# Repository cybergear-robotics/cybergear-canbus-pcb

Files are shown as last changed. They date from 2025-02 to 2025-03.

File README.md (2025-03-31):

# CyberGear CAN-Bus PCB




This is a small extension board located on the CyberBot. It distributes the
CAN-bus to all 6 cybergears and provides a debug port. Each cybergear CAN-bus sink can
be switched between CAN-bus or debug port. The can-bus is designed as star
topology, which works in small setups. 

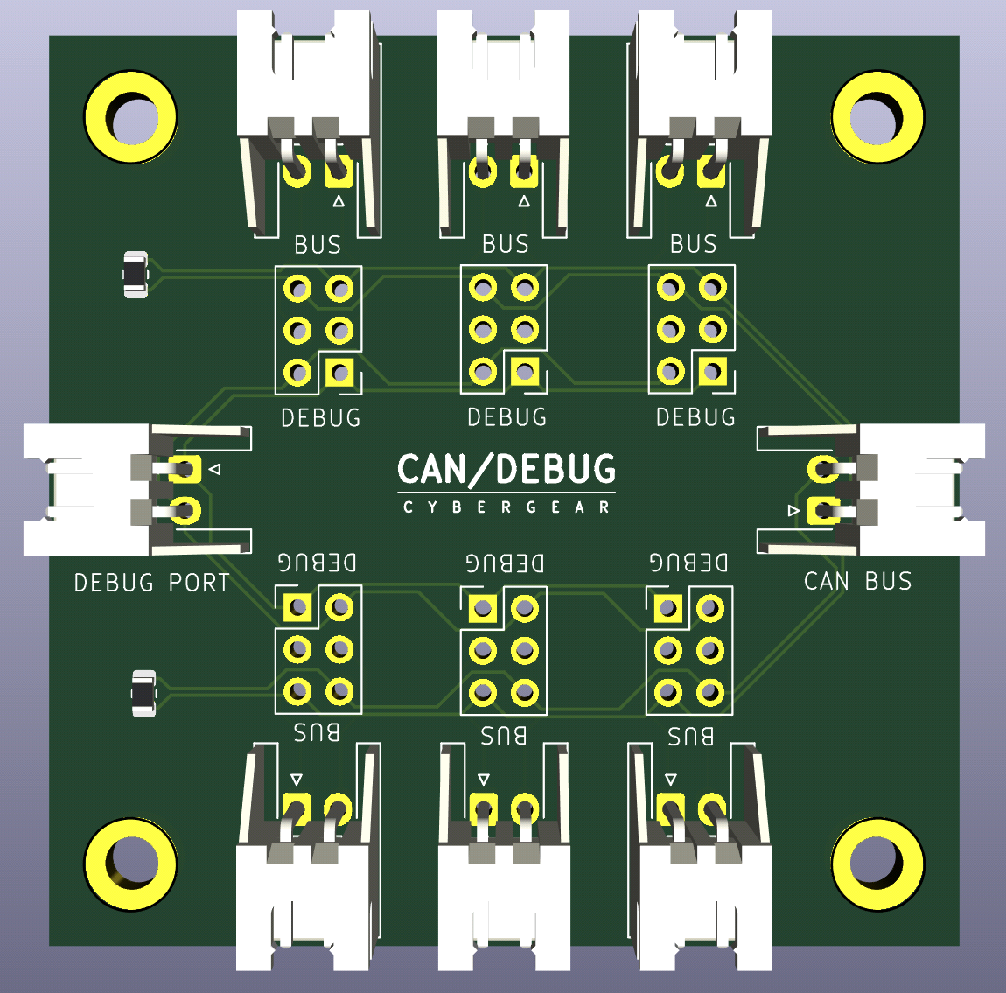
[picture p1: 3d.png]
3D


## DIP switches

The switches are missing in the production files and you need to solder these on your
own. The required switches are MSS22D18 Mini DIP Slide Switch 2x03.

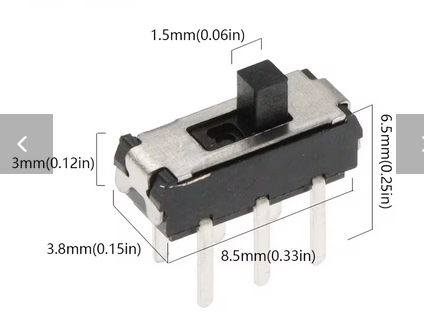
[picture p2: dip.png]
dip


## Debug Port

The debug port is connected to a special CAN to USB adapter. There is no product
number. I only could find one offer on Aliexpress for around 12 euros:

```
USB-TTL/RS232/RS485/CAN Serial Communication Module CH340 CP2102 Data Conversion
Transparent Transmission Standard Protocol
```

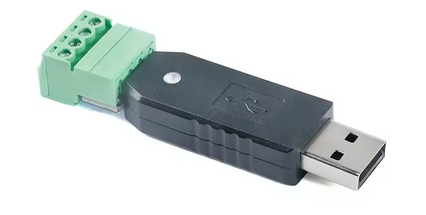
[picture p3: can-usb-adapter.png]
can-usb-adapter


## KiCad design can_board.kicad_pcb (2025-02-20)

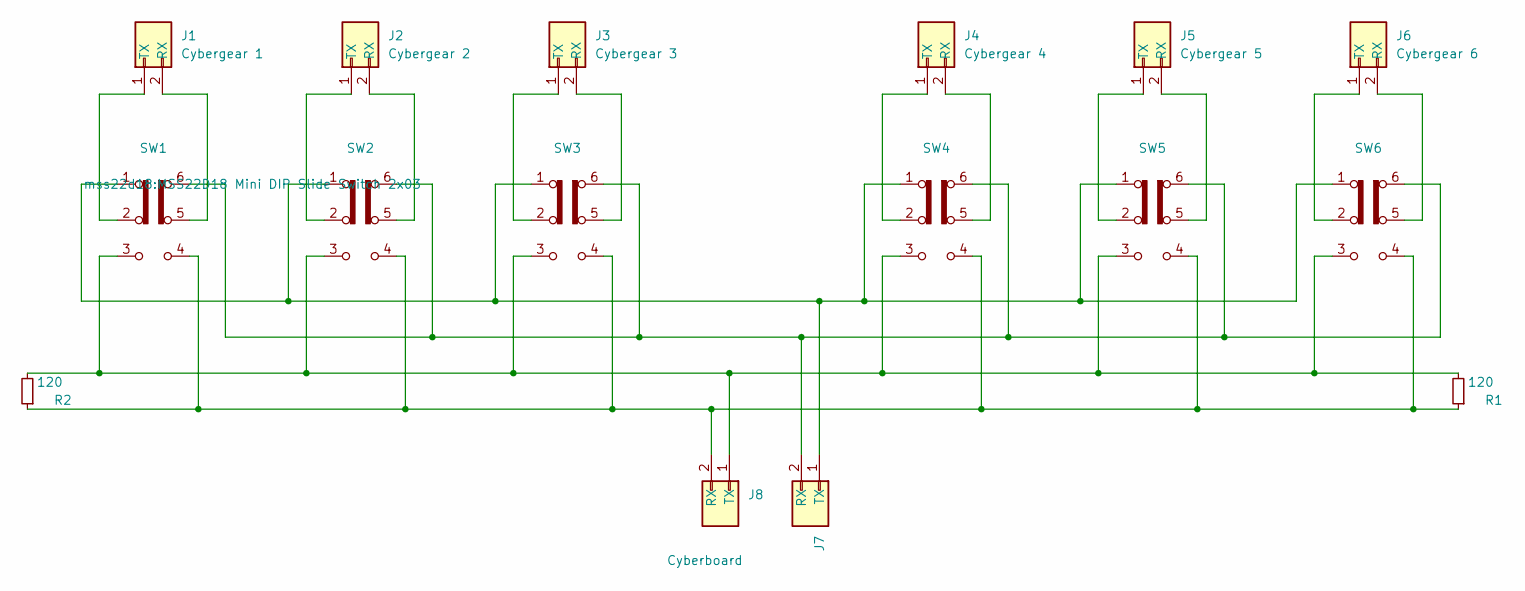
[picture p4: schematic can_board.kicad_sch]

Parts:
J1: Cybergear 1; JST_XH_S2B-XH-A-1_1x02_P2.50mm_Horizontal
J2: Cybergear 2; JST_XH_S2B-XH-A-1_1x02_P2.50mm_Horizontal
J3: Cybergear 3; JST_XH_S2B-XH-A-1_1x02_P2.50mm_Horizontal
J4: Cybergear 4; JST_XH_S2B-XH-A-1_1x02_P2.50mm_Horizontal
J5: Cybergear 5; JST_XH_S2B-XH-A-1_1x02_P2.50mm_Horizontal
J6: Cybergear 6; JST_XH_S2B-XH-A-1_1x02_P2.50mm_Horizontal
J7: Debug; JST_XH_S2B-XH-A-1_1x02_P2.50mm_Horizontal
J8: Cyberboard; JST_XH_S2B-XH-A-1_1x02_P2.50mm_Horizontal
R1, R2: 120; R_0805_2012Metric; LCSC C17437
SW1, SW2, SW3, SW4, SW5, SW6: SW_Slide_DPDT; MSS22D18 Mini DIP Slide Switch 2x03

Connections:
unnamed: J1.2 (RX), SW1.5 (B)
unnamed: J1.1 (TX), SW1.2 (B)
unnamed: J2.2 (RX), SW2.5 (B)
unnamed: J2.1 (TX), SW2.2 (B)
unnamed: J3.2 (RX), SW3.5 (B)
unnamed: J3.1 (TX), SW3.2 (B)
unnamed: J4.2 (RX), SW4.5 (B)
unnamed: J4.1 (TX), SW4.2 (B)
unnamed: J5.2 (RX), SW5.5 (B)
unnamed: J5.1 (TX), SW5.2 (B)
unnamed: J6.2 (RX), SW6.5 (B)
unnamed: J6.1 (TX), SW6.2 (B)
unnamed: J7.2 (RX), SW1.6 (C), SW2.6 (C), SW3.6 (C), SW4.6 (C), SW5.6 (C), SW6.6 (C)
unnamed: J7.1 (TX), SW1.1 (A), SW2.1 (A), SW3.1 (A), SW4.1 (A), SW5.1 (A), SW6.1 (A)
unnamed: J8.2 (RX), R1.1, R2.1, SW1.4 (A), SW2.4 (A), SW3.4 (A), SW4.4 (A), SW5.4 (A), SW6.4 (A)
unnamed: J8.1 (TX), R1.2, R2.2, SW1.3 (C), SW2.3 (C), SW3.3 (C), SW4.3 (C), SW5.3 (C), SW6.3 (C)

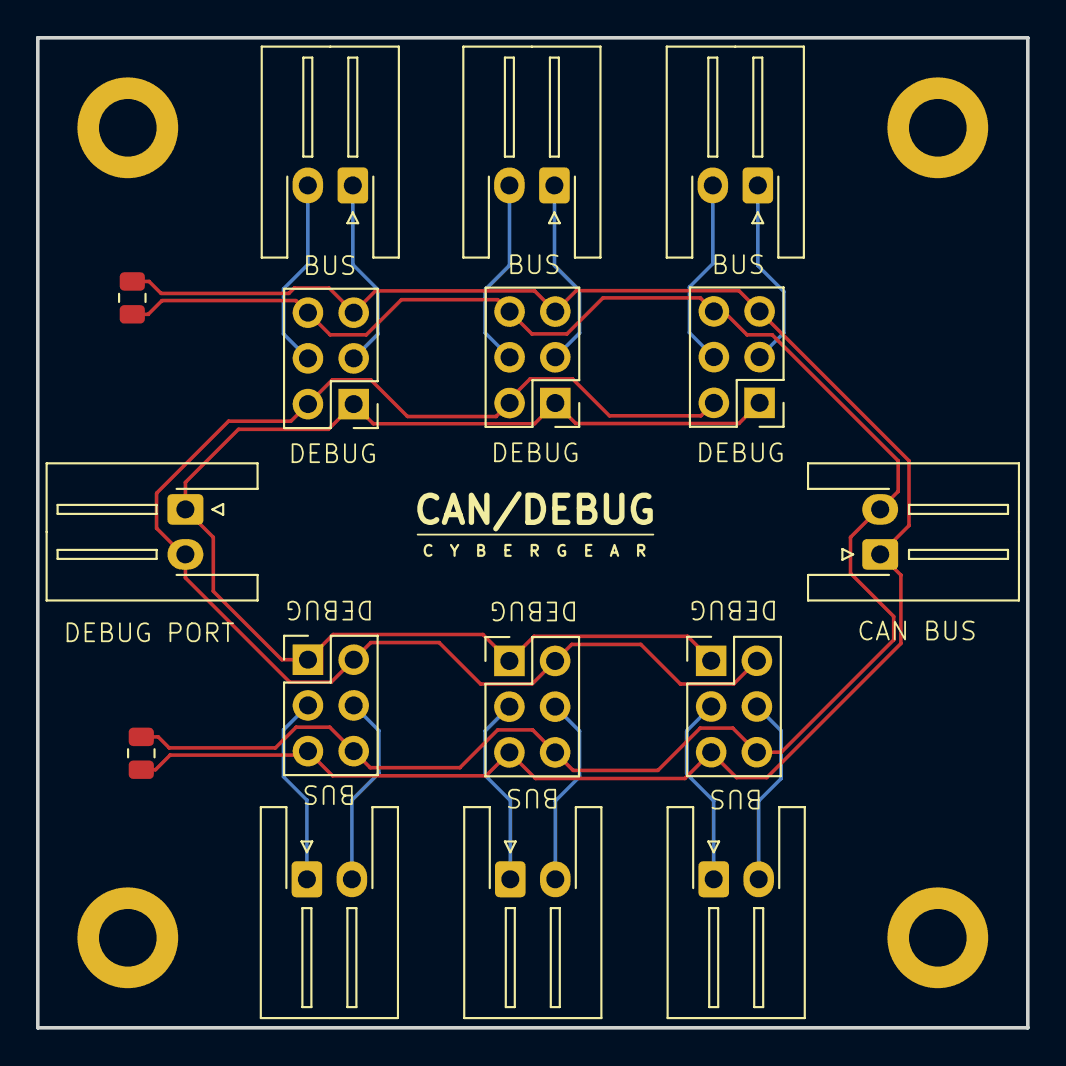
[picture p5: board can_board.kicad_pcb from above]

Board: 2 copper layers, 55.0 x 55.0 mm, 20 parts (0 on the bottom side), 16 nets.

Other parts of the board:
H1, H2, H3, H4: MountingHole_Pad; MountingHole_3.2mm_M3_DIN965_Pad

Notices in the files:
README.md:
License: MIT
